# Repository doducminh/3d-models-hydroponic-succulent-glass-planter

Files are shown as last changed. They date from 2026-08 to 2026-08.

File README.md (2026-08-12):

# Hydroponic Succulent Planter for a Glass Tumbler

A two-part 3D-printed insert that lets you grow succulents **hydroponically** inside
an ordinary glass tumbler. The roots stay submerged; the plants sit above the water
line on a perforated top plate.

Designed for a tumbler with a slanted cut rim, but the parts drop into any glass
with an inner mouth diameter of **90 mm or more**.

## Preview

[`viewer/index.html`](viewer/index.html) shows both parts assembled, on a scaled
225 × 225 mm print bed. Download it and double-click — it needs no web server and no
local files, the geometry is packed into the page itself. It is the same mesh as the
STL files, not a simplified stand-in.

To publish it on the web, enable GitHub Pages (Settings → Pages → Source: main,
folder `/`) and it becomes browsable at `/viewer/`.

Two further pages are **speculative design studies**, not products — nothing on them
is printable yet. They exist to test ideas against the numbers before any CAD is drawn.

[`viewer/v3-tilted-tray.html`](viewer/v3-tilted-tray.html) is the live one: a single
tray leaning on the glass's slanted rim, carrying six *level* pots that each hold a
reserve of water when the pump is off.

[`viewer/v2-tower.html`](viewer/v2-tower.html) is a two-tier airlift tower, **dropped**.
An uplift tube has to stay about 70 % submerged, and a 74 mm deep reservoir caps the
discharge near 104 mm while the second tier needs 149 mm. Kept because a rejected idea
with a reason attached is worth more than a deleted one.

## Parts

| File | Size | Weight (PETG, solid) | Print orientation |
|---|---|---|---|
| `stl/top-plate.stl` | 84 × 84 × 4.9 mm | 13.9 g | flat, as exported |
| `stl/mesh-base.stl` | 91.2 × 91.2 × 73 mm | 48.9 g | upright, as exported |

Both files are watertight, single-body, and already in the correct print
orientation. **No supports needed.**

**Top plate** — Ø84 disc, 3 mm thick, with a gently domed surface. Four Ø26
planting holes on a 23 mm radius, four decorative cut-outs (heart, star, flower,
balloon) on a 32 mm radius, and a Ø12 centre hole for topping up water.

**Mesh base** — a tapered skirt going from Ø76 at the top down to Ø60 at the foot,
67 mm tall, 3 mm walls, pierced by 43 randomly scattered cut-outs including a
capybara. It self-centres on the curved bottom of the glass. Three Ø4 holes around
the foot let you thread a line through to tie down a weight.

The top plate drops into the neck of the base with 0.5 mm of clearance per side.

## Print settings

Printed on an Elegoo Neptune 4, 0.4 mm nozzle.

| | |
|---|---|
| Material | **PETG** — PLA hydrolyses and turns brittle in permanent water contact |
| Nozzle | 240 °C |
| Bed | 80 °C |
| Layer height | 0.2 mm |
| Perimeters | 4 |
| Infill | 25 % gyroid |
| Brim | 5 mm for the mesh base; none needed for the top plate |
| Supports | **None** |

## Assembly and use

1. Rinse all soil off the root balls — required for hydroponics, and it shrinks the
   root ball enough to fit the holes.
2. Drop the mesh base into the glass, then seat the top plate in its neck.
3. Fill with water plus hydroponic nutrient, up to just below the top plate.
4. Set the plants into the Ø26 holes. Small plants and leaf cuttings will fall
   through — use a net pot or pack moss around the collar.
5. Optional: an aquarium air stone in the base keeps the water oxygenated, which
   the roots need.

Change the water every few days; nutrient concentrates as water evaporates.

## Notes

- The Ø26 holes are sized for a **root ball**, not for individual roots. This is
  the single most important dimension in the design.
- A Ø84 disc fits at most five Ø26 holes — pure geometry. Six plants need a
  multi-tier design.
- Printed unsupported, the top of each round hole sags slightly. It is cosmetic and
  does not affect function.

## Licence

[CC BY-NC-SA 4.0](LICENSE) — share and remix freely for non-commercial use, credit
the author, share alike.

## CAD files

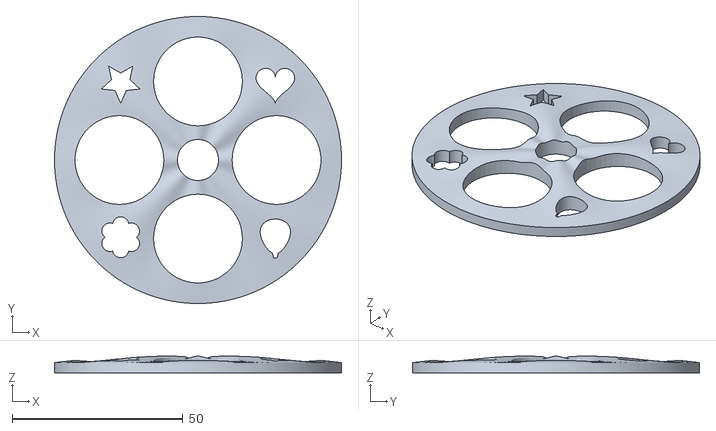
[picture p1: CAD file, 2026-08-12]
stl/top-plate.stl
84.0 x 84.0 x 4.90

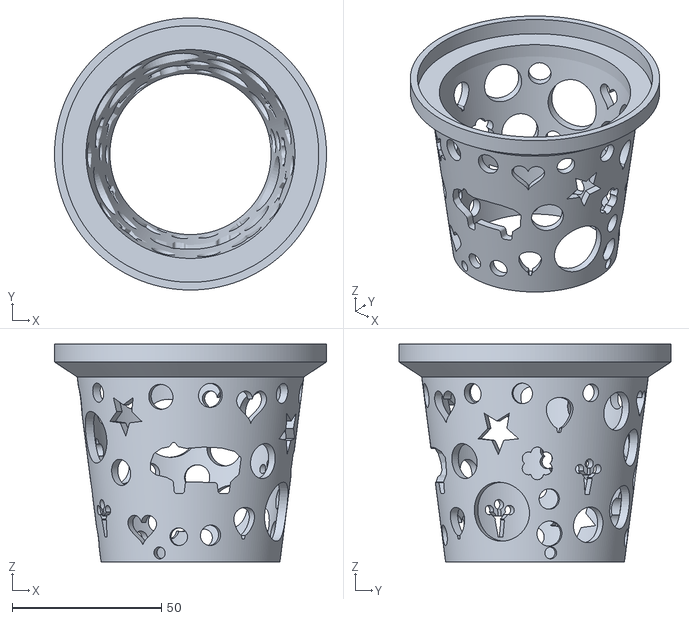
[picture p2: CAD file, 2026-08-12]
stl/mesh-base.stl
91.2 x 91.2 x 73.0

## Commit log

2026-08-12 Add hydroponic-succulent-glass-planter: printable files, README, licence
    [mesh-base.stl, top-plate.stl]
2026-08-12 Viewer: embed geometry so it works from disk, and show parts assembled
2026-08-12 Rework the airlift to the real uplift-tube arrangement; lobed tiers
2026-08-12 Sunken merged basin, centre trellis, air-pump-viable defaults
2026-08-12 Sua loi hinh hoc: dung chau bang mot luoi lien thay vi chong khoi roi
    Ban truoc SAI hoan toan ve hinh hoc, khong phai chi xau:
    - "mam" chi la tam phang day 3mm co lo hinh hoa, khong phai long chau
    - "vay" la khoi dac O112 day 46mm treo tu z=52 den z=98 -> DAM XUYEN THANH LY
    (ly chi rong O90)
    - "san hoc" la may cai dia tron lo lung, khong vach noi, cam xuyen moi thu
    Nguyen nhan: toi chi nhin anh chup tu tren xuong, thay hinh hoa roi cho la dat,
    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
2026-08-12 Tilted wells with spoon bases, three-part assembly, flower rim
2026-08-13 Five wells, machinery at the back, real through-holes
2026-08-13 Blossom rim, woven lattice foot, holes sized to the measured root ball
2026-08-13 Cherry-blossom rim with cleft petals; solid skirt with cute cut-outs
2026-08-13 Bigger foot, crisp shaped cut-outs with real wall thickness
2026-08-13 Add a flower-stem cover for the air hose
2026-08-13 Fix hole scatter silently dropping holes
